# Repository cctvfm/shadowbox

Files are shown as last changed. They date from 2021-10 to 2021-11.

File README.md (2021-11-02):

# shadowbox
Shadowbox is an Open Source optically controlled digital drone synth where parameters are controlled by introducing or blocking light. Based on Emilie Gillet's Plaits Module.

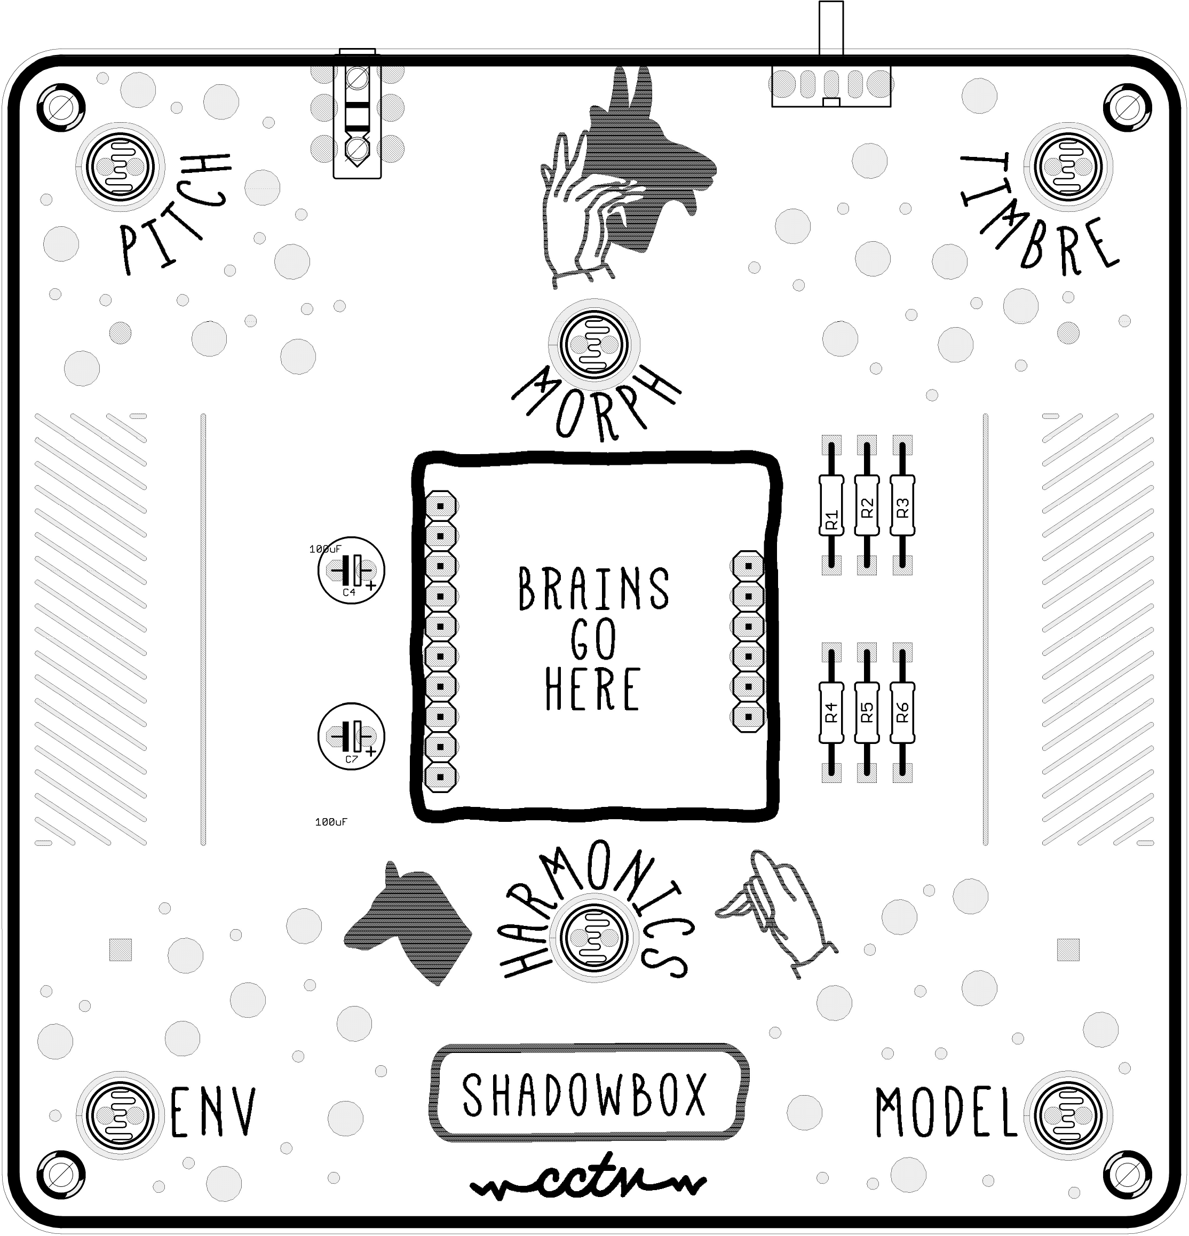
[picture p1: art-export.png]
Main PCB


To Compile code:

Copy entire 'neuzplaits' folder into the 'eurorack' folder in the mutable dev environment.

run 

make -f neuzplaits/bootloader/makefile hex

make -f neuzplaits/makefile

to upload using ST-Link V2:

make -f neuzplaits/makefile upload

'AVR CHICLET' is an alternate brain board using ATMEGA328P. Code to come.

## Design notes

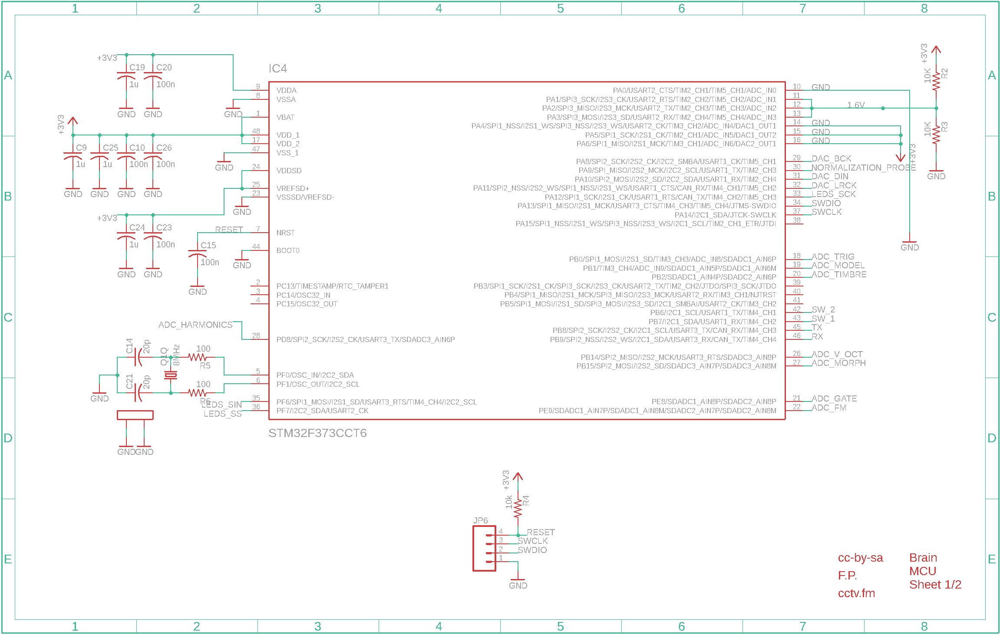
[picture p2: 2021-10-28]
schematic-brain1.png

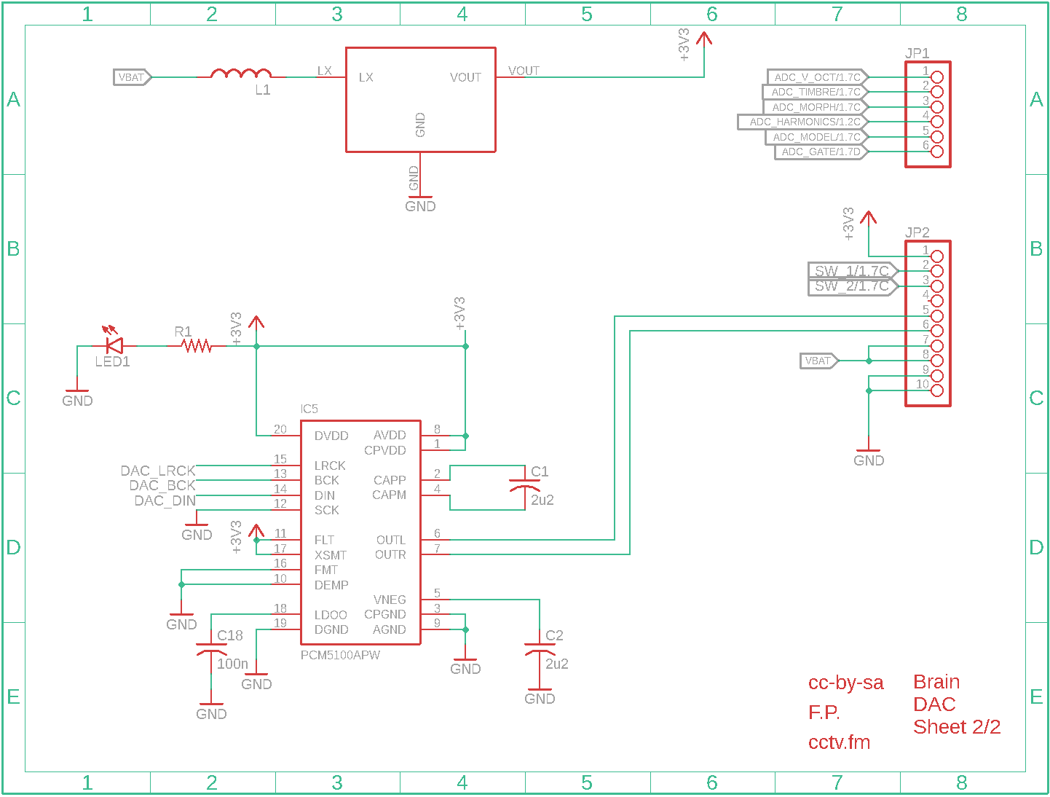
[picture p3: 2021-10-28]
schematic-brain2.png

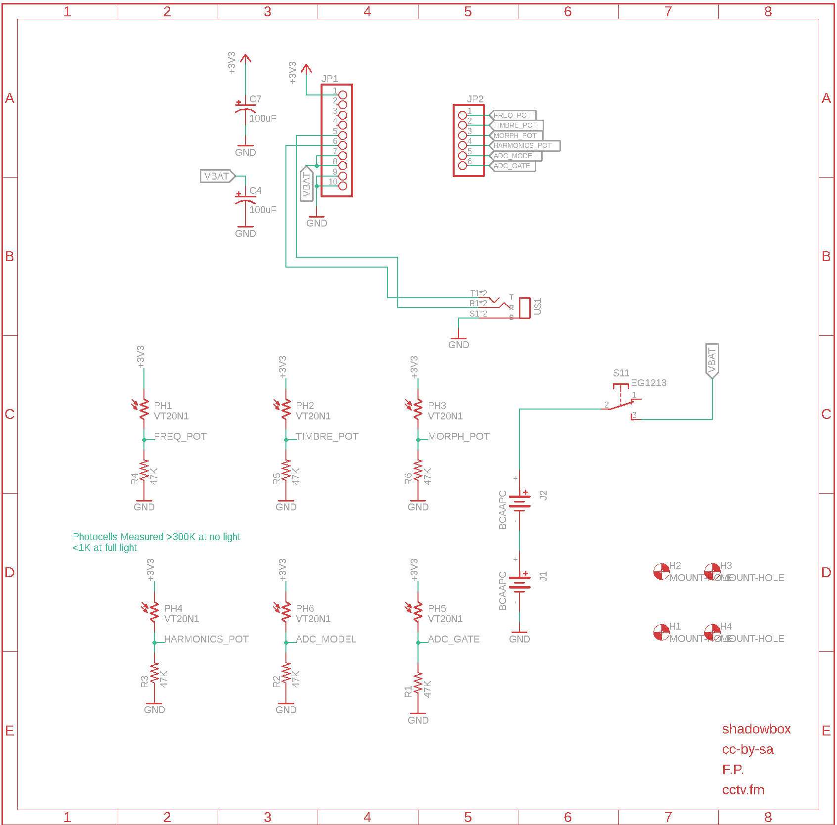
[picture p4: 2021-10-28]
schematic.png

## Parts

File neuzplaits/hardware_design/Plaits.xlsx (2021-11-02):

Plaits, v5.0
Index | Qty | Description | Specs | Value | Package | Ref. Mouser | References
SMT parts
R3, R4, R16, R21, R45, R48, R49, R50, R51 | 9 | Resistor | <=1%, 100mW | 10k | 0402 | 667-ERJ-2RKF1002X
R5, R6, R9, R10 | 4 | Resistor | <=1%, 100mW | 100 | 0402 | 667-ERJ-2RKF1000X
R11, R12, R37 | 3 | Resistor | <=1%, 100mW | 2.2k | 0402 | 667-ERJ-2RKF2201X
R13, R14, R15, R24, R38, R39, R40, R41 | 8 | Resistor | <=1%, 100mW | 100k | 0402 | 667-ERJ-2RKF1003X
R17 | 1 | Resistor | <=1%, 100mW | 56k | 0402 | 667-ERJ-2RKF5602X
R18, R20, R22, R28, R31, R34 | 6 | Resistor | <=1%, 100mW | 33k | 0402 | 667-ERJ-2RKF3302X
R19, R32, R35 | 3 | Resistor | <=1%, 100mW | 20k | 0402 | 667-ERJ-2RKF2002X
R23, R33, R36 | 3 | Resistor | <=1%, 100mW | 120k | 0402 | 667-ERJ-2RKF1203X
R25, R27, R30 | 3 | Resistor | <=1%, 100mW | 200k | 0402 | 667-ERJ-2RKF2003X
R26 | 1 | Resistor | <=1%, 100mW | 110k | 0402 | 667-ERJ-2RKF1103X
R29 | 1 | Resistor | <=1%, 100mW | 140k | 0402 | 667-ERJ-2RKF1403X
R46, R47 | 2 | Resistor | <= 1%, >= 200mW | 1.0k | 0603 | 667-ERJ-PA3D1001V | Panasonic ERJ-PA3D1001V
C1, C2, C13 | 3 | Capacitor, ceramic | >= 25V, X5R | 22u | 1206 | 81-GRM31CR61E226ME5L | Murata GRM31CR61E226ME15L
C3, C7, C16, C22, C30 | 5 | Capacitor, electrolytic | >= 16V | 10u | Panasonic A (3mm) | 647-UWX1C100MCL2 | Nichicon UWX1C100MCL2GB
C4, C5 | 2 | Capacitor, electrolytic | >= 35V | 22u | Panasonic B (4mm) | 647-UCM1V220MCL1GS | Nichicon UCM1V220MCL1GS
C6, C8, C10, C11, C12, C15, C17, C18, C20, C23, C26, C27, C28, C32, C34, C36, C37, C44, C45, C51, C52, C53 | 22 | Capacitor, ceramic | >= 25V, X5R | 100n | 0402 | 81-GRM155R61E104KA7D | Murata GRM155R61E104KA87D
C9, C19, C24, C25, C50 | 5 | Capacitor, ceramic | >= 25V, X6S | 1u | 0402 | 81-GRM155C81E105ME1D | Murata GRM155C81E105ME11D
C14, C21 | 2 | Capacitor, ceramic | >=25V, C0G, <= 5% | 20p | 0402 | 81-GRM1555C1E200JA1D | Murata GRM1555C1E200JA01D
C29, C31 | 2 | Capacitor, ceramic | >= 25V, X5R | 2.2u | 0805 | 810-C2012X5R1E225K | TDK C2012X5R1E225K125AC
C33, C35, C39, C40, C41, C47, C48, C49 | 8 | Capacitor, ceramic | >= 25V, C0G, <= 5% | 1n | 0402 | 81-GRM1555C1H102JA1D | Murata GRM1555C1H102JA01D
C38, C42, C43, C46 | 4 | Capacitor, ceramic | >= 25V, C0G, <= 5% | 100p | 0402 | 81-GRM1555C1H101JA1D | Murata GRM1555C1H101JA01D
C54, C55, C56, C57, C58, C59, C60, C61 | 8 | Ceradiode |  |  | 0603 | 871-B72500D160H60 | Epcos / TDK B72500D160H60
L1 | 1 | Inductor |  | 33u | 0805 | 810-MLZ2012M330WT000 | TDK MLZ2012M330WT000
L2, L3, L4, L5 | 4 | EMI Filter Bead | >= 1k ohm, 300mA |  | 0603 | 710-742792664 | Würth Electronics 742792664
D1, D2 | 2 | 1N5819HW diode |  |  | SOD123 | 621-1N5819HW-F | Diodes Inc 1N5819HW-7-F
D3 | 1 | BAT54SLT1G diode |  |  | SOT23 | 863-BAT54SLT1G | ON Semi BAT54SLT1G (replaces BAT54S)
IC2 | 1 | TLC59281DBQ 16ch LED driver |  |  | TSSOP24 | 595-TLC59281DBQR | Texas Instruments TLC59281DBQR
IC3 | 1 | LD2981ABU33 LDO regulator | 3.3V |  | SOT89-3 | 511-LD2981ABU33 | ST LD2981ABU33TR
IC4 | 1 | STM32F373CCT6, Cortex M4 256k flash |  |  | LQFP48 | 511-STM32F373CCT6 | ST STM32F373CCT6
IC5 | 1 | PCM5100APW Audio DAC |  |  | SSOP20 | 595-PCM5100APWR | Texas Instruments PCM5100APWR
IC6, IC7 | 2 | MCP6004 quad op-amp R2R IO |  |  | TSSOP14 | 579-MCP6004-I/ST | Microchip MCP6004-I/ST
IC8 | 1 | TL072 dual op-amp |  |  | TSSOP8 | 595-TL072CPWR | Texas Instruments TL072CPWR
IC9 | 1 | LM4040 Shunt Vref | C grade (0.5%, 100ppm) | 10V | SOT23 | 595-LM4040C10IDBZR | Texas Instruments LM4040C10IDBZ
Q1 | 1 | Crystal | <= 20ppm | 8MHz | 6mm x 3.6mm | 815-ABMM2-8-E2T | Abracon ABMM2-8.000MHZ-E2-T
PTH parts, top side
IC1 | 1 | DC-DC converter R-78E3.3-0.5 | 3.3V, 500mA |  |  | 919-R-78E3.3-0.5 | Recom R-78E3.3-0.5
J1, J2, J3, J4, J5, J6, J7, J8, J9, J10 | 10 | Vertical jack connector |  |  |  |  | https://www.thonk.co.uk/shop/thonkiconn/
LED1, LED2, LED3, LED4, LED5, LED6, LED7, LED8 | 8 | LED 3mm red/green common anode |  |  |  | 696-SSLLX3059IGWCA | Lumex SSL-LX3059IGW-CA
- | 8 | LED holder, 0.3in |  |  |  | 749-ERM1-300 | Bivar ERM 1-300
R1, R2, R7, R8 | 4 | 10k linear pot, 15mm shaft |  |  |  |  | https://www.thonk.co.uk/shop/alpha-9mm-pots/
R42, R43, R44 | 3 | 10k linear pot, 25mm shaft with marker |  |  |  |  | https://www.thonk.co.uk/shop/ttpots/
SW1, SW2 | 2 | Switch, 6mm |  |  |  | 612-TL1105SP-250 | E-switch TL1105SPF250Q
- | 2 | Cap for switch |  |  |  | 612-1R-BK | E-switch 1RBLK
PTH parts, bottom side
JP8 | 1 | 2x5 male boxed header, 2.54mm pitch |  |  |  | 710-61201021621
PCB |  | 59.0 x 106.7

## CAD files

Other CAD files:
neuzplaits/hardware_design/panel/plaits_v50.dwg

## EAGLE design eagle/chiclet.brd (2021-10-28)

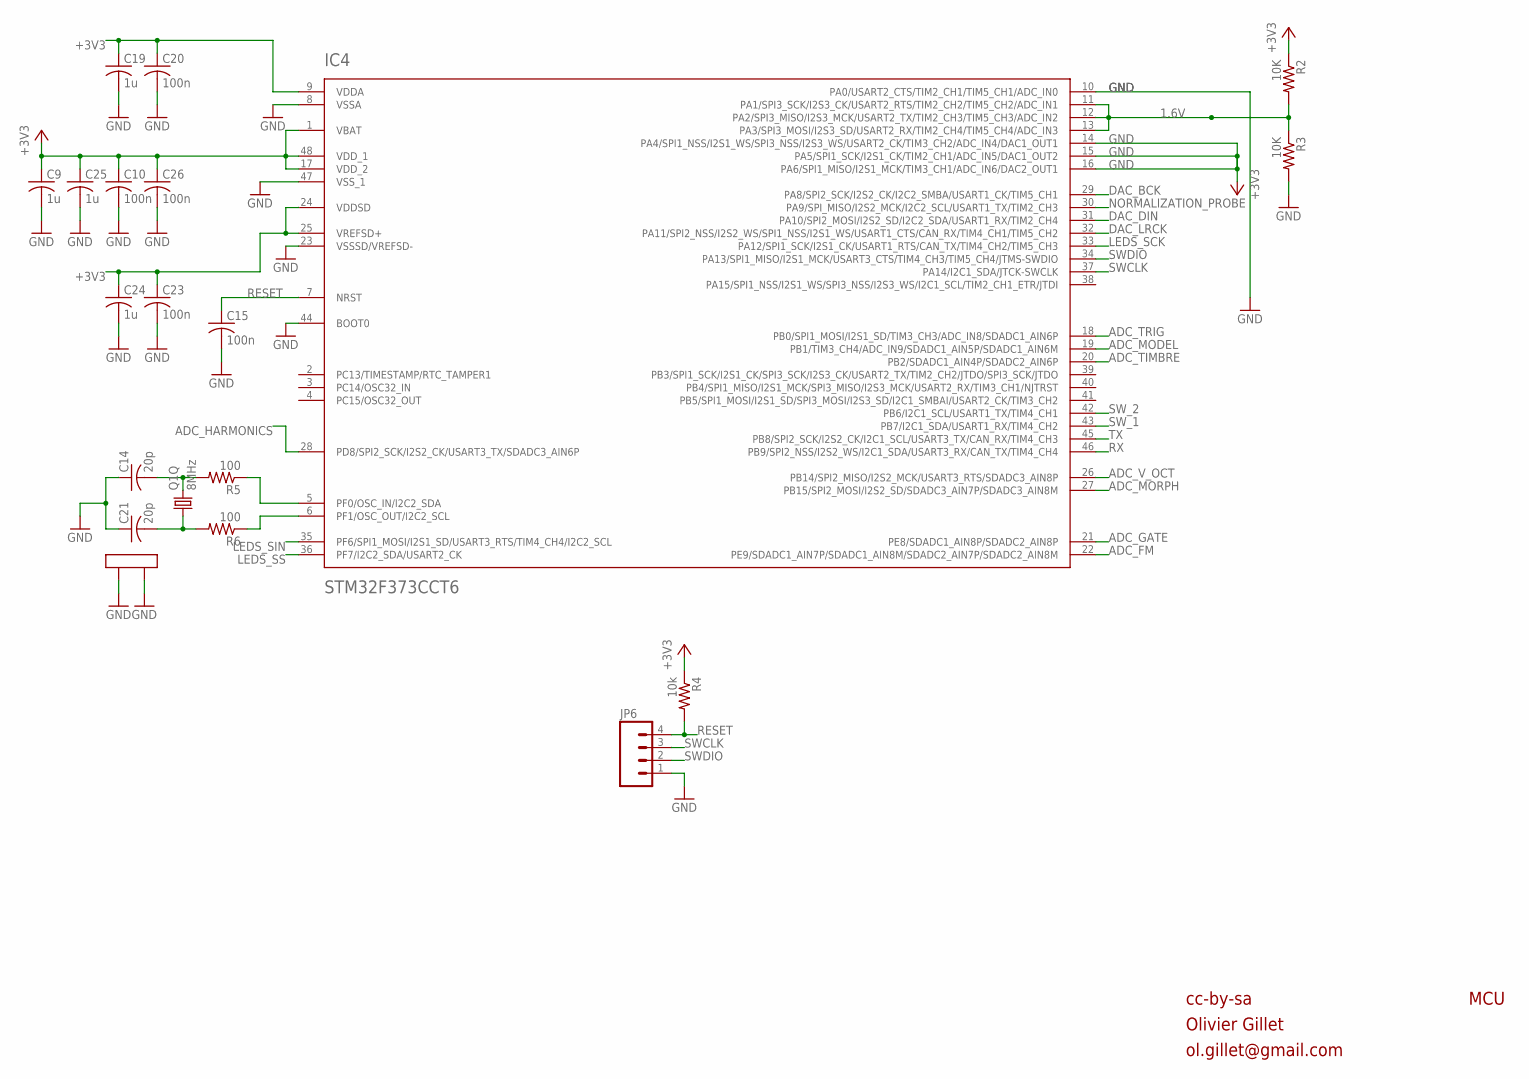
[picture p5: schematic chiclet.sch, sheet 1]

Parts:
C9, C19, C24, C25: 1u; C0805
C10, C15, C20, C23, C26: 100n; C0805
C14, C21: 20p; C0805
IC4: STM32F373CCT6; LQFP48
JP6: M04PTH; 1X04
Q1: 8MHz; CTS406
R2, R3: 10K; M0805
R4: 10k; M0805
R5, R6: 100; M0805

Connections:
1.6V: IC4.11 (PA1/SPI3_SCK/I2S3_CK/USART2_RTS/TIM2_CH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), IC4.12 (PA2/SPI3_MISO/I2S3_MCK/USART2_TX/TIM2_C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), IC4.13 (PA3/SPI3_MOSI/I2S3_SD/USART2_RX/TIM2_CH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), R2.2, R3.1
+3V3: C9.1, C10.1, C19.1, C20.1, C23.1, C24.1, C25.1, C26.1, IC4.1 (VBAT), IC4.9 (VDDA), IC4.14 (PA4/SPI1_NSS/I2S1_WS/SPI3_NSS/I2S3_WS/U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), IC4.15 (PA5/SPI1_SCK/I2S1_CK/TIM2_CH1/ADC_IN5/D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), IC4.16 (PA6/SPI1_MISO/I2S1_MCK/TIM3_CH1/ADC_IN6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), IC4.17 (VDD_2), IC4.24 (VDDSD), IC4.25 (VREFSD+), IC4.48 (VDD_1), R2.1, R4.1; also elsewhere on the board
ADC_FM: IC4.22 (PE9/SDADC1_AIN7P/SDADC1_AIN8M/SDADC2_AI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)
ADC_GATE: IC4.21 (PE8/SDADC1_AIN8P/SDADC2_AIN8P); also elsewhere on the board
ADC_HARMONICS: IC4.28 (PD8/SPI2_SCK/I2S2_CK/USART3_TX/SDADC3_A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); also elsewhere on the board
ADC_MODEL: IC4.19 (PB1/TIM3_CH4/ADC_IN9/SDADC1_AIN5P/SDADC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); also elsewhere on the board
ADC_MORPH: IC4.27 (PB15/SPI2_MOSI/I2S2_SD/SDADC3_AIN7P/SDA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); also elsewhere on the board
ADC_TIMBRE: IC4.20 (PB2/SDADC1_AIN4P/SDADC2_AIN6P); also elsewhere on the board
ADC_TRIG: IC4.18 (PB0/SPI1_MOSI/I2S1_SD/TIM3_CH3/ADC_IN8/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)
ADC_V_OCT: IC4.26 (PB14/SPI2_MISO/I2S2_MCK/USART3_RTS/SDAD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); also elsewhere on the board
DAC_BCK: IC4.29 (PA8/SPI2_SCK/I2S2_CK/I2C2_SMBA/USART1_C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); also elsewhere on the board
DAC_DIN: IC4.31 (PA10/SPI2_MOSI/I2S2_SD/I2C2_SDA/USART1_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); also elsewhere on the board
DAC_LRCK: IC4.32 (PA11/SPI2_NSS/I2S2_WS/SPI1_NSS/I2S1_WS/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); also elsewhere on the board
GND: C9.2, C10.2, C14.1, C15.2, C19.2, C20.2, C21.1, C23.2, C24.2, C25.2, C26.2, IC4.8 (VSSA), IC4.10 (PA0/USART2_CTS/TIM2_CH1/TIM5_CH1/ADC_IN0), IC4.23 (VSSSD/VREFSD-), IC4.44 (BOOT0), IC4.47 (VSS_1), JP6.1, Q1.2 (LID1), Q1.4 (LID2), R3.2; also elsewhere on the board
LEDS_SCK: IC4.33 (PA12/SPI1_SCK/I2S1_CK/USART1_RTS/CAN_TX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)
LEDS_SIN: IC4.35 (PF6/SPI1_MOSI/I2S1_SD/USART3_RTS/TIM4_C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)
LEDS_SS: IC4.36 (PF7/I2C2_SDA/USART2_CK)
unnamed: IC4.5 (PF0/OSC_IN/I2C2_SDA), R5.1
unnamed: IC4.6 (PF1/OSC_OUT/I2C2_SCL), R6.1
unnamed: C14.2, Q1.3 (2), R5.2
unnamed: C21.2, Q1.1, R6.2
NORMALIZATION_PROBE: IC4.30 (PA9/SPI_MISO/I2S2_MCK/I2C2_SCL/USART1_T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)
RESET: C15.1, IC4.7 (NRST), JP6.4, R4.2
RX: IC4.46 (PB9/SPI2_NSS/I2S2_WS/I2C1_SDA/USART3_RX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)
SWCLK: IC4.37 (PA14/I2C1_SDA/JTCK-SWCLK), JP6.3
SWDIO: IC4.34 (PA13/SPI1_MISO/I2S1_MCK/USART3_CTS/TIM4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), JP6.2
SW_1: IC4.43 (PB7/I2C1_SDA/USART1_RX/TIM4_CH2); also elsewhere on the board
SW_2: IC4.42 (PB6/I2C1_SCL/USART1_TX/TIM4_CH1); also elsewhere on the board
TX: IC4.45 (PB8/SPI2_SCK/I2S2_CK/I2C1_SCL/USART3_TX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)

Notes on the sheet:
cc-by-sa
Olivier Gillet
ol.gillet@gmail.com
MCU

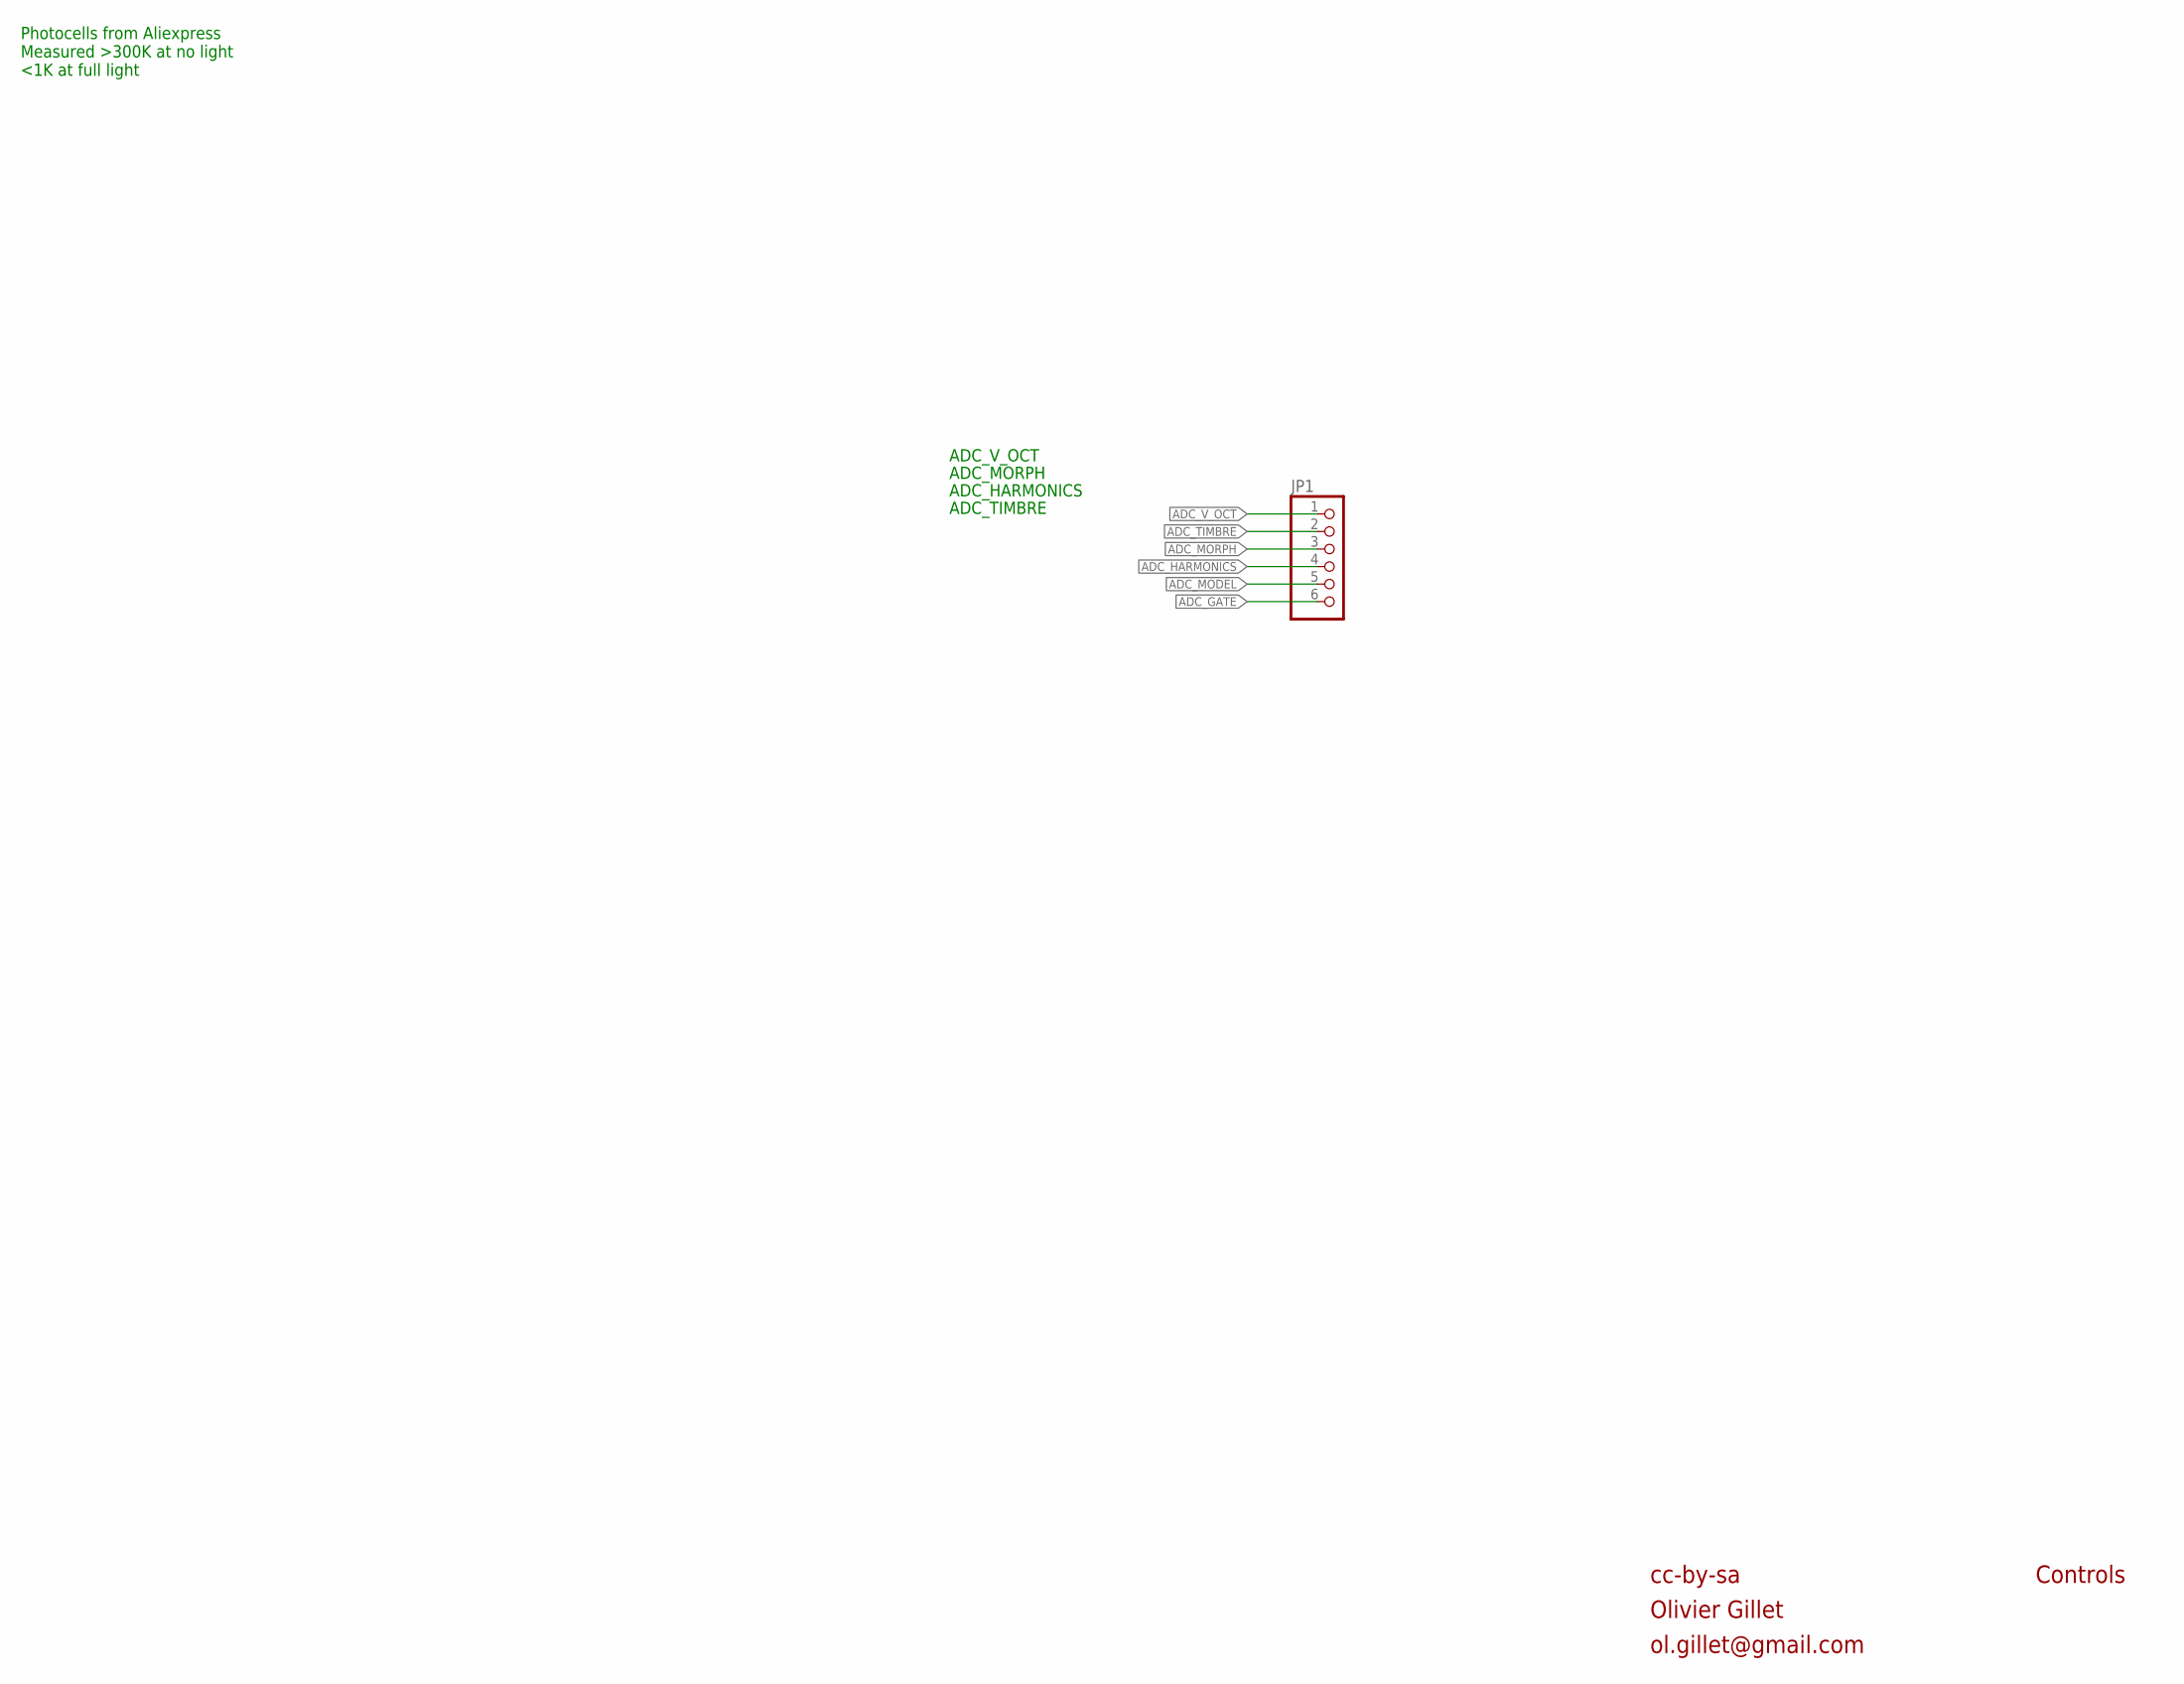
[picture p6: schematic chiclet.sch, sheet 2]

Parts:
JP1: PINHD-1X6; 1X06

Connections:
ADC_GATE: JP1.6; also elsewhere on the board
ADC_HARMONICS: JP1.4; also elsewhere on the board
ADC_MODEL: JP1.5; also elsewhere on the board
ADC_MORPH: JP1.3; also elsewhere on the board
ADC_TIMBRE: JP1.2; also elsewhere on the board
ADC_V_OCT: JP1.1; also elsewhere on the board

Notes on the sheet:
cc-by-sa
Olivier Gillet
ol.gillet@gmail.com
Controls
Photocells from Aliexpress Measured >300K at no light <1K at full light
ADC_V_OCT
ADC_MORPH
ADC_HARMONICS
ADC_TIMBRE

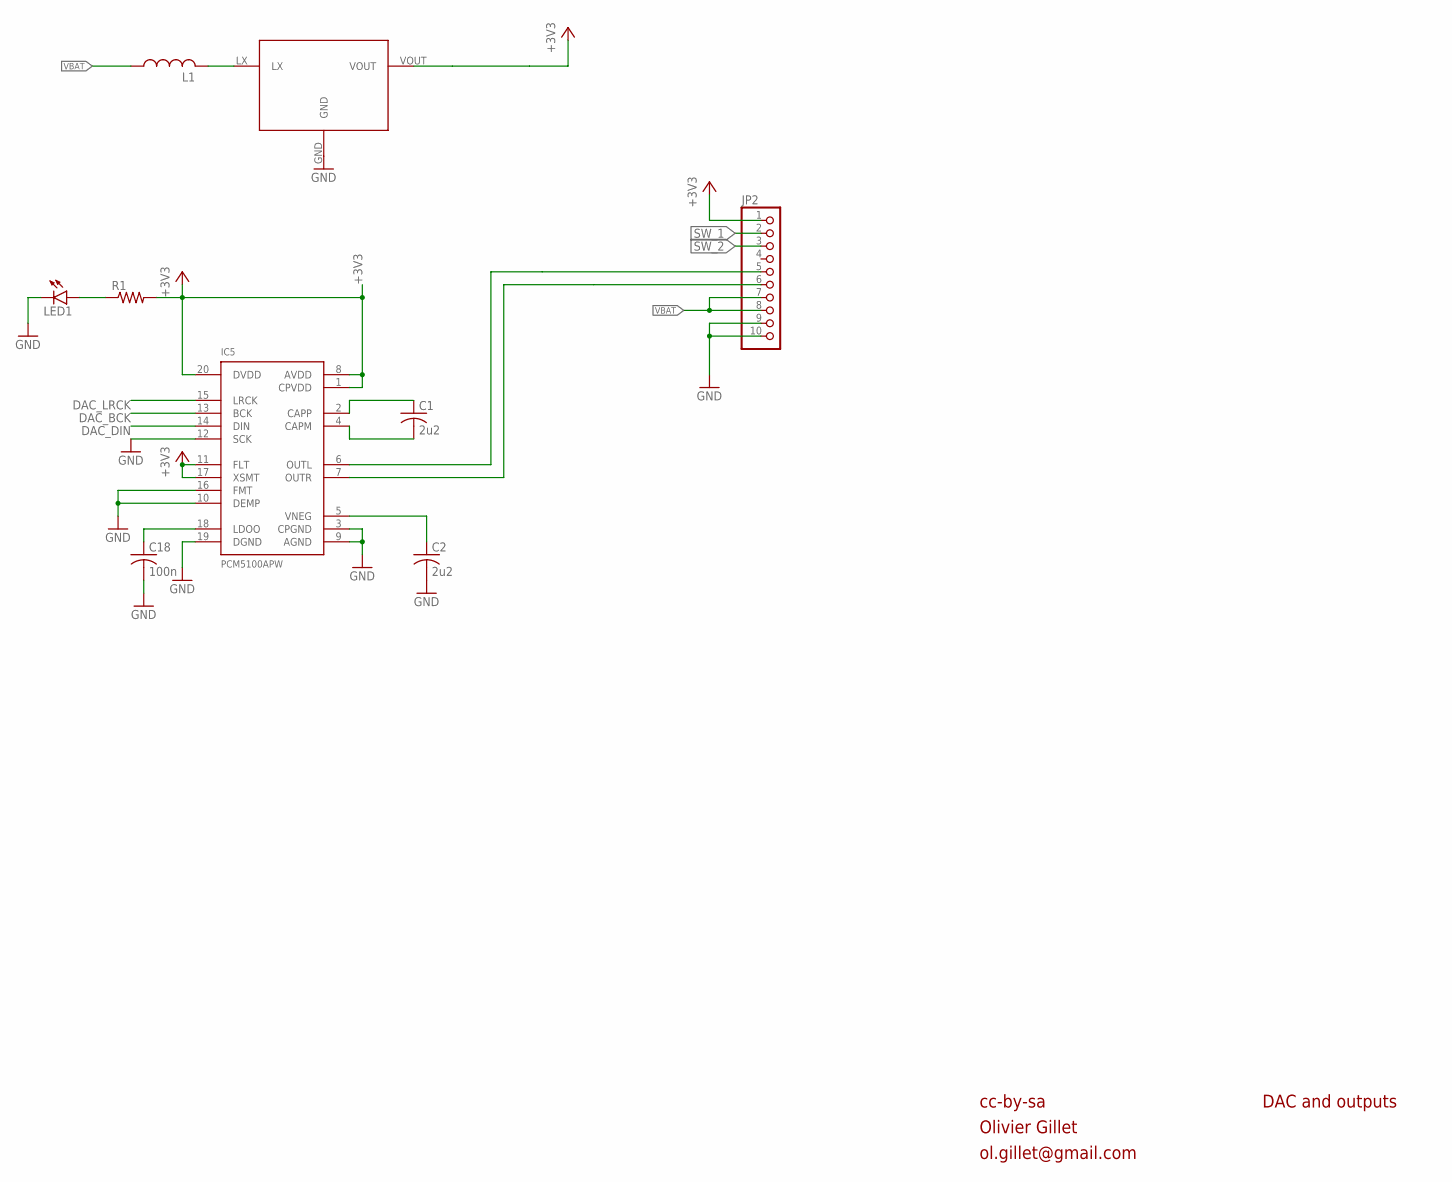
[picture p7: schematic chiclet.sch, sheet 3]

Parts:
C1, C2: 2u2; C0805K
C18: 100n; C0805K
IC5: PCM5100APW; SSOP20
JP2: PINHD-1X10; 1X10
L1: L-USL2825P; L2825P
LED1: LEDSML0805; SML0805
R1: R-US_R0805; R0805
U$1: QX2304L33E; SOT89-R

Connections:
+3V3: IC5.1 (CPVDD), IC5.8 (AVDD), IC5.11 (FLT), IC5.17 (XSMT), IC5.20 (DVDD), JP2.1, R1.2, U$1.VOUT; also elsewhere on the board
DAC_BCK: IC5.13 (BCK); also elsewhere on the board
DAC_DIN: IC5.14 (DIN); also elsewhere on the board
DAC_LRCK: IC5.15 (LRCK); also elsewhere on the board
GND: C2.2, C18.2, IC5.3 (CPGND), IC5.9 (AGND), IC5.10 (DEMP), IC5.12 (SCK), IC5.16 (FMT), IC5.19 (DGND), JP2.9, JP2.10, LED1.C, U$1.GND; also elsewhere on the board
unnamed: LED1.A, R1.1
unnamed: C2.1, IC5.5 (VNEG)
unnamed: L1.2, U$1.LX
unnamed: C1.1, IC5.2 (CAPP)
unnamed: IC5.6 (OUTL), JP2.5
unnamed: IC5.7 (OUTR), JP2.6
unnamed: C1.2, IC5.4 (CAPM)
unnamed: C18.1, IC5.18 (LDOO)
SW_1: JP2.2; also elsewhere on the board
SW_2: JP2.3; also elsewhere on the board
VBAT: JP2.7, JP2.8, L1.1

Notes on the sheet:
cc-by-sa
Olivier Gillet
ol.gillet@gmail.com
DAC and outputs

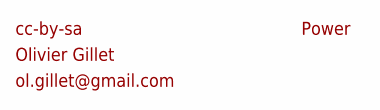
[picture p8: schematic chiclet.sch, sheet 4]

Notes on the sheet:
cc-by-sa
Olivier Gillet
ol.gillet@gmail.com
Power

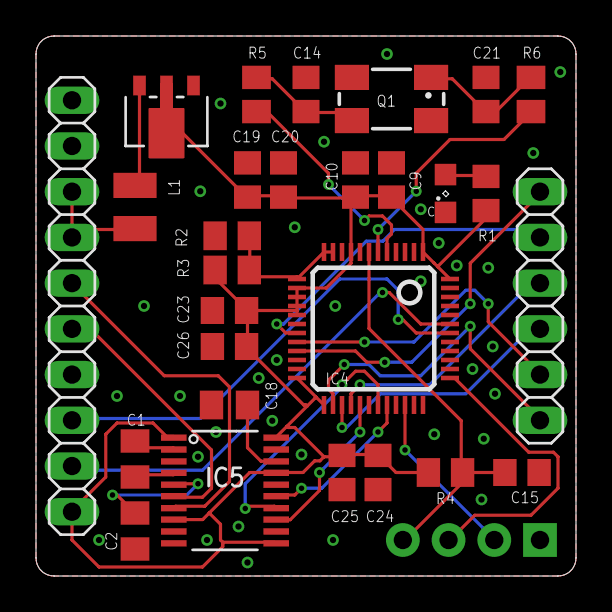
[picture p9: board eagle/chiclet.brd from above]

Board: 2 copper layers, 30.0 x 30.0 mm, 29 parts (1 on the bottom side), 30 nets.

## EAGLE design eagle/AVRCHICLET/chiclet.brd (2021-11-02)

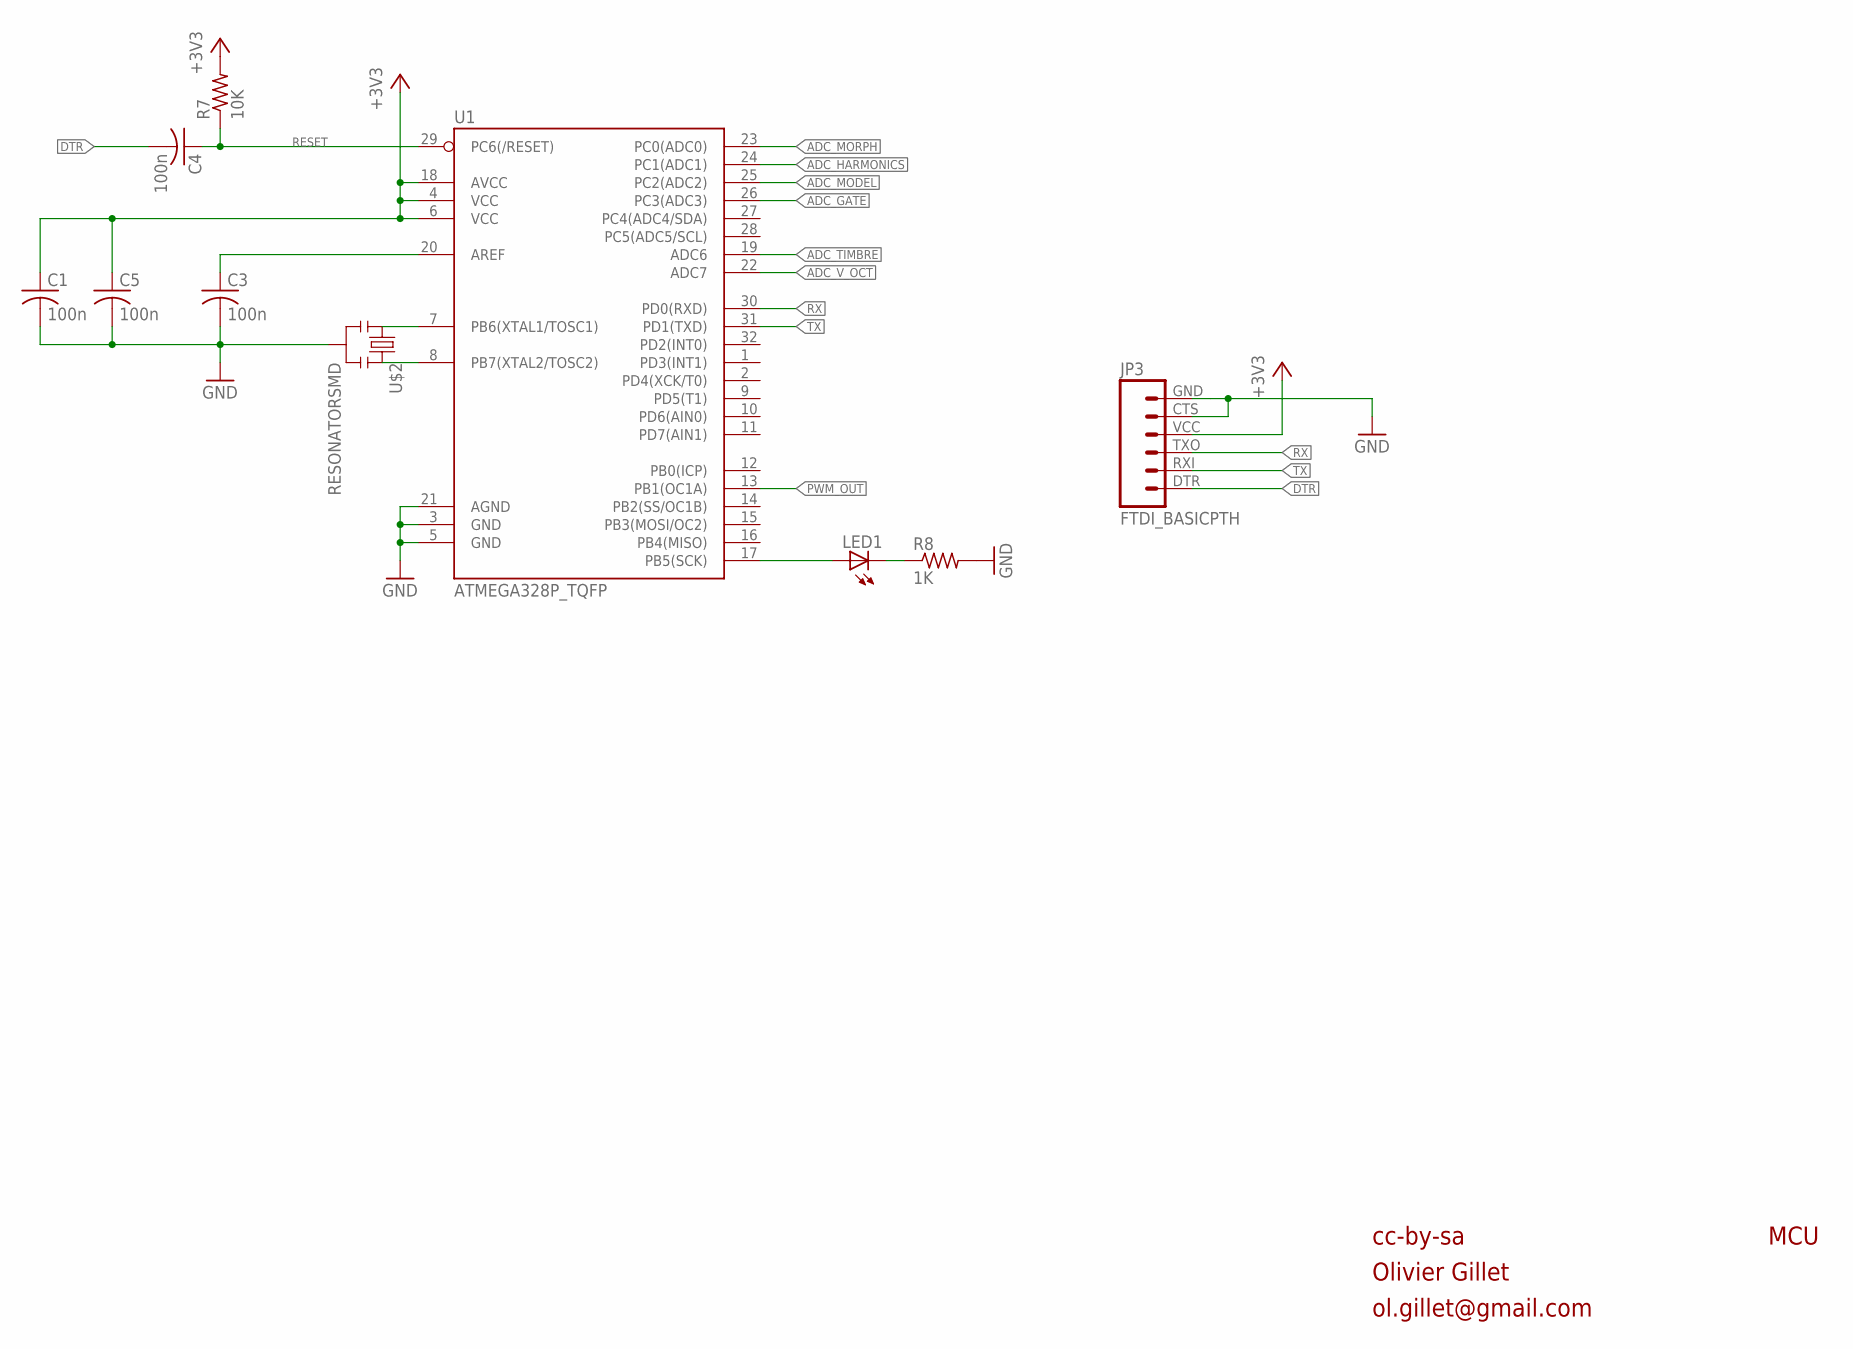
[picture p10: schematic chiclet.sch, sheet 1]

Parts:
C1, C3, C4, C5: 100n; C0805
JP3: FTDI_BASICPTH; FTDI_BASIC
LED1: LED-0805; LED-805
R7: 10K; M0805
R8: 1K; M0805
U1: ATMEGA328P_TQFP; TQFP32-08
U$2: RESONATORSMD; RESONATOR-SMD

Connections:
+3V3: C1.1, C5.1, JP3.VCC (4), R7.2, U1.4 (VCC), U1.6 (VCC), U1.18 (AVCC); also elsewhere on the board
ADC_GATE: U1.26 (PC3(ADC3)); also elsewhere on the board
ADC_HARMONICS: U1.24 (PC1(ADC1)); also elsewhere on the board
ADC_MODEL: U1.25 (PC2(ADC2)); also elsewhere on the board
ADC_MORPH: U1.23 (PC0(ADC0)); also elsewhere on the board
ADC_TIMBRE: U1.19 (ADC6); also elsewhere on the board
ADC_V_OCT: U1.22 (ADC7); also elsewhere on the board
DTR: C4.2, JP3.DTR (1)
GND: C1.2, C3.2, C5.2, JP3.CTS (5), JP3.GND (6), R8.2, U1.3 (GND), U1.5 (GND), U1.21 (AGND), U$2.2; also elsewhere on the board
unnamed: U1.7 (PB6(XTAL1/TOSC1)), U$2.1
unnamed: U1.8 (PB7(XTAL2/TOSC2)), U$2.3
unnamed: C3.1, U1.20 (AREF)
unnamed: LED1.A, U1.17 (PB5(SCK))
unnamed: LED1.C, R8.1
PWM_OUT: U1.13 (PB1(OC1A)); also elsewhere on the board
RESET: C4.1, R7.1, U1.29 (PC6(/RESET))
RX: JP3.TXO (3), U1.30 (PD0(RXD))
TX: JP3.RXI (2), U1.31 (PD1(TXD))

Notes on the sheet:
cc-by-sa
Olivier Gillet
ol.gillet@gmail.com
MCU


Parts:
JP1: PINHD-1X6; 1X06

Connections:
ADC_GATE: JP1.6; also elsewhere on the board
ADC_HARMONICS: JP1.4; also elsewhere on the board
ADC_MODEL: JP1.5; also elsewhere on the board
ADC_MORPH: JP1.3; also elsewhere on the board
ADC_TIMBRE: JP1.2; also elsewhere on the board
ADC_V_OCT: JP1.1; also elsewhere on the board

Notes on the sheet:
cc-by-sa
Olivier Gillet
ol.gillet@gmail.com
Controls
Photocells from Aliexpress Measured >300K at no light <1K at full light
ADC_V_OCT
ADC_MORPH
ADC_HARMONICS
ADC_TIMBRE

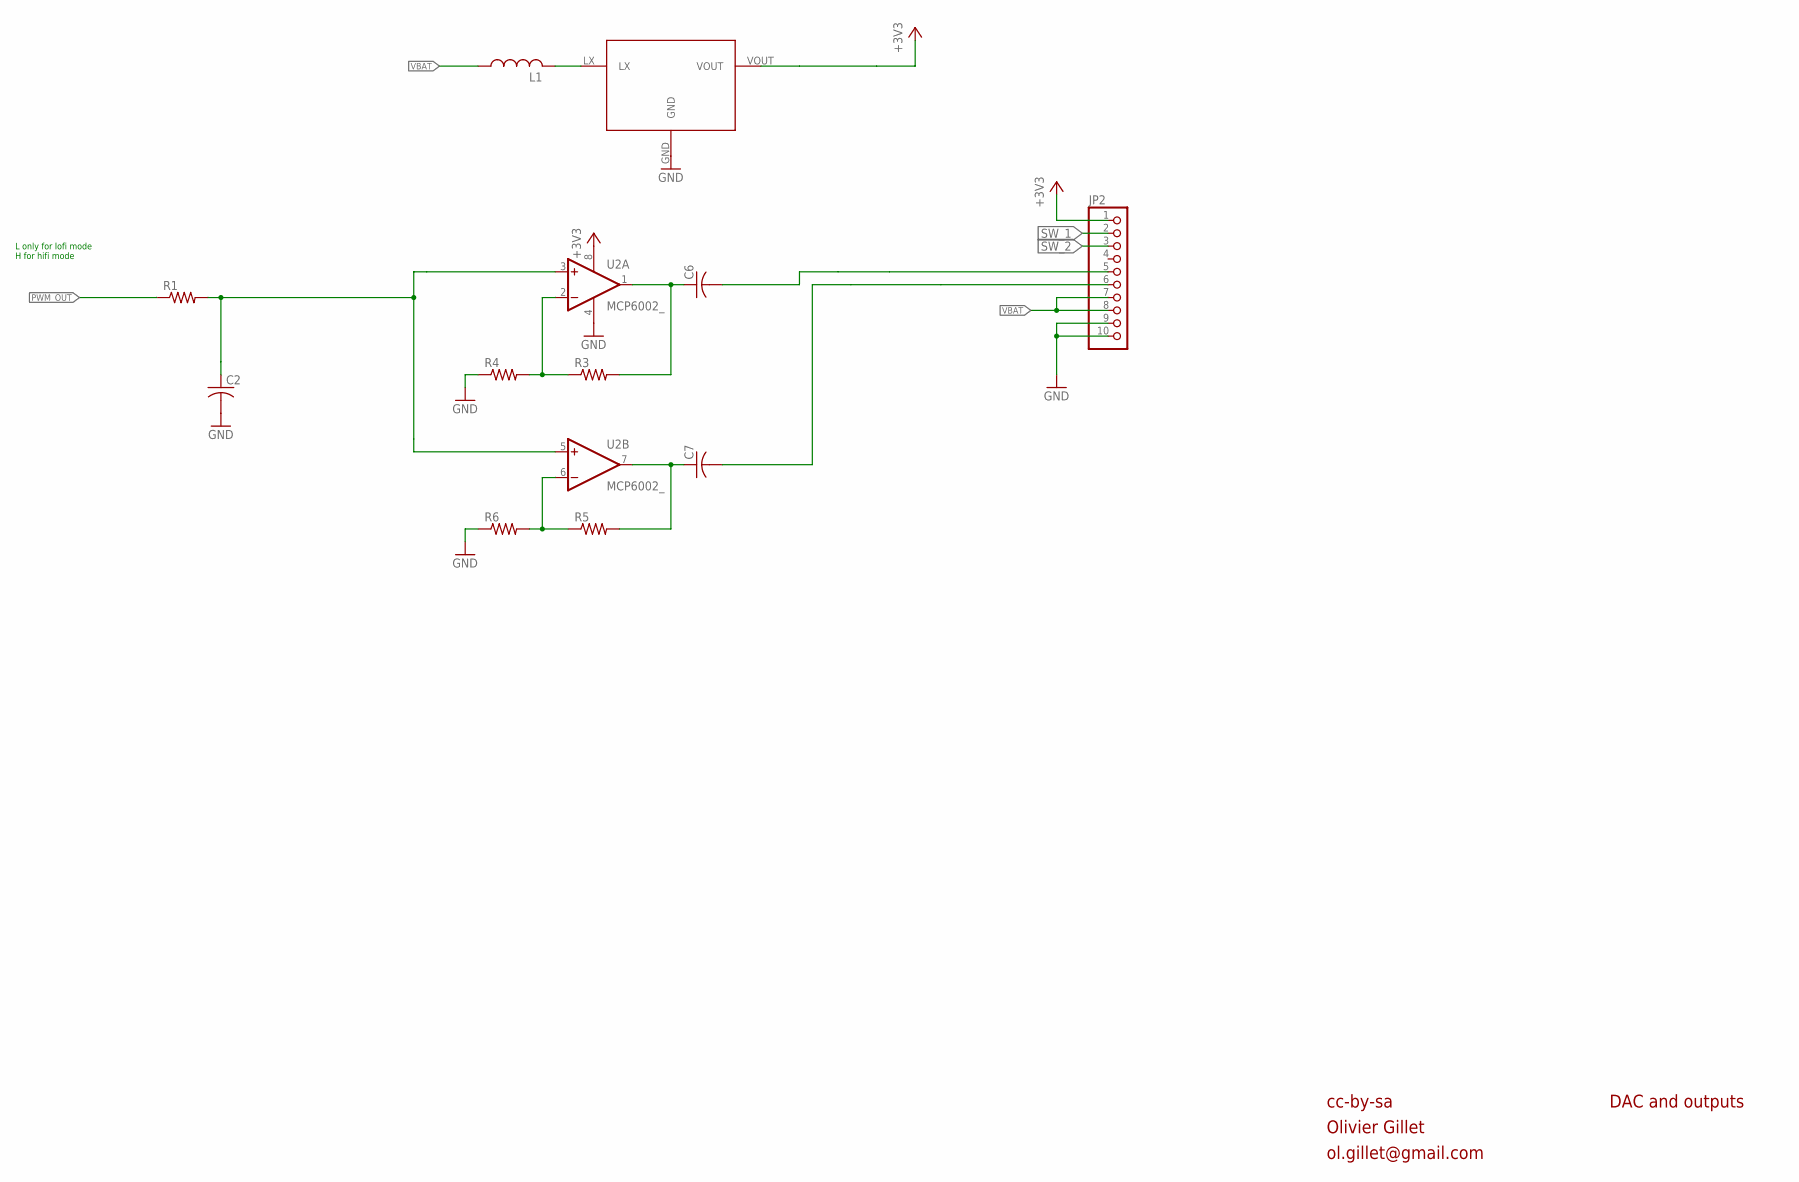
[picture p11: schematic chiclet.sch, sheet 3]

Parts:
C2, C6, C7: C-USC0805; C0805
JP2: PINHD-1X10; 1X10
L1: L-USL2825P; L2825P
R1, R3, R4, R5, R6: R-US_R0805; R0805
U2: MCP6002_; SO08
U$1: QX2304L33E; SOT89-R

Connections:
+3V3: JP2.1, U2.8 (V+), U$1.VOUT; also elsewhere on the board
GND: C2.2, JP2.9, JP2.10, R4.1, R6.1, U2.4 (V-), U$1.GND; also elsewhere on the board
unnamed: L1.2, U$1.LX
unnamed: C2.1, R1.2, U2.3 (+IN), U2.5 (+IN)
unnamed: C6.2, JP2.5
unnamed: C7.2, JP2.6
unnamed: R3.1, R4.2, U2.2 (-IN)
unnamed: R5.1, R6.2, U2.6 (-IN)
unnamed: C7.1, R5.2, U2.7 (OUT)
unnamed: C6.1, R3.2, U2.1 (OUT)
PWM_OUT: R1.1; also elsewhere on the board
SW_1: JP2.2
SW_2: JP2.3
VBAT: JP2.7, JP2.8, L1.1

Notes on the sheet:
cc-by-sa
Olivier Gillet
ol.gillet@gmail.com
DAC and outputs
L only for lofi mode H for hifi mode

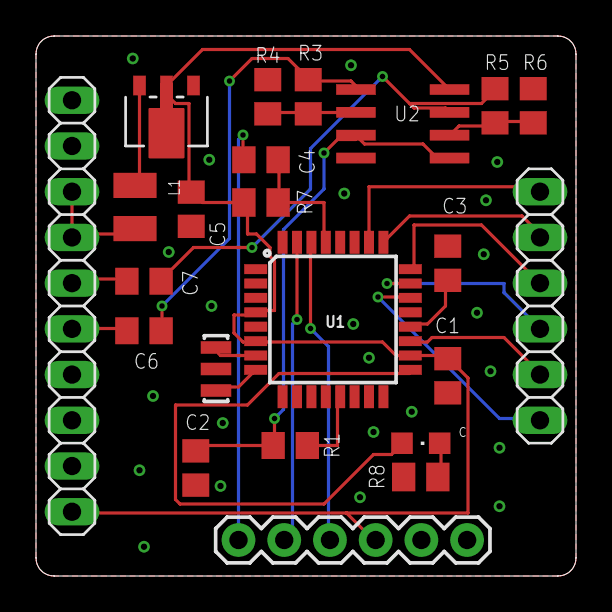
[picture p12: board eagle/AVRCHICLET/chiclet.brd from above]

Board: 2 copper layers, 30.0 x 30.0 mm, 23 parts (0 on the bottom side), 27 nets.

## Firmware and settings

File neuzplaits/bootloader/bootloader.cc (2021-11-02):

// Copyright 2016 Emilie Gillet.
// 
// Author: Emilie Gillet (emilie.o.gillet@gmail.com)
// 
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
// See http://creativecommons.org/licenses/MIT/ for more information.

#include <stm32f37x_conf.h>
#include <cstring>

#include "stmlib/system/bootloader_utils.h"
#include "stmlib/system/flash_programming.h"
#include "stmlib/system/system_clock.h"

#include "stm_audio_bootloader/qpsk/packet_decoder.h"
#include "stm_audio_bootloader/qpsk/demodulator.h"

#include "plaits/drivers/audio_dac.h"
#include "plaits/drivers/firmware_update_adc.h"
#include "plaits/drivers/leds.h"
#include "plaits/drivers/switches.h"

extern "C" {

void NMI_Handler() { }
void HardFault_Handler() { while (1); }
void MemManage_Handler() { while (1); }
void BusFault_Handler() { while (1); }
void UsageFault_Handler() { while (1); }
void SVC_Handler() { }
void DebugMon_Handler() { }
void PendSV_Handler() { }

}

using namespace plaits;
using namespace std;
using namespace stm_audio_bootloader;
using namespace stmlib;

const double kSampleRate = 48000.0;
const double kModulationRate = 6000.0;
const double kBitRate = 12000.0;
const uint32_t kStartAddress = 0x08008000;
const uint16_t kPacketsPerPage = PAGE_SIZE / kPacketSize;

enum UiState {
  UI_STATE_WAITING,
  UI_STATE_RECEIVING,
  UI_STATE_ERROR,
  UI_STATE_WRITING
};

AudioDac audio_dac;
FirmwareUpdateAdc adc;
Leds leds;
Switches switches;
PacketDecoder decoder;
Demodulator demodulator;

int discard_samples = 8000;
int32_t peak = 0;
int32_t gain_pot = 0;
uint32_t current_address;
uint16_t packet_index;
uint8_t rx_buffer[PAGE_SIZE];

volatile bool switch_released = false;
volatile UiState ui_state;

inline void UpdateLeds() {
  leds.Clear();
  
  // Show bargraph on the upper 4 LEDs.
  int32_t pwm = system_clock.milliseconds() & 15;
  leds.set(3, (peak >> 9) > pwm ? LED_COLOR_GREEN : 0);
  leds.set(2, ((peak - 8192) >> 9) >= pwm ? LED_COLOR_GREEN : 0);
  leds.set(1, ((peak - 16384) >> 9) >= pwm ? LED_COLOR_YELLOW : 0);
  leds.set(0, ((peak - 16384 - 8192) >> 9) >= pwm ? LED_COLOR_RED : 0);
  
  // Show status info on the lower 4 LEDs.
  switch (ui_state) {
    case UI_STATE_WAITING:
      {
        bool on = system_clock.milliseconds() & 128;
        for (int i = 4; i < 8; ++i) {
          leds.set(i, on ? LED_COLOR_YELLOW : LED_COLOR_OFF);
        }
      }
      break;

    case UI_STATE_RECEIVING:
      {
        int stage = (system_clock.milliseconds() >> 7) & 3;
        leds.set(stage + 4, LED_COLOR_GREEN);
      }
      break;

    case UI_STATE_ERROR:
      {
        bool on = system_clock.milliseconds() & 256;
        for (int i = 0; i < 8; ++i) {
          leds.set(i, on ? LED_COLOR_RED : LED_COLOR_OFF);
        }
      }
      break;

    case UI_STATE_WRITING:
      {
        for (uint8_t i = 4; i < 8; ++i) {
          leds.set(i, LED_COLOR_GREEN);
        }
      }
      break;
    }
  leds.Write();
}

extern "C" {
  
void SysTick_Handler() {
  system_clock.Tick();
  switches.Debounce();
  if (switches.released(Switch(0))) {
    switch_released = true;
  }
  UpdateLeds();
}
  
}

void ProgramPage(const uint8_t* data, size_t size) {
  FLASH_Unlock();
  FLASH_ErasePage(current_address);
  const uint32_t* words = static_cast<const uint32_t*>(
      static_cast<const void*>(data));
  for (size_t written = 0; written < size; written += 4) {
    FLASH_ProgramWord(current_address, *words++);
    current_address += 4;
  }
}

void FillBuffer(AudioDac::Frame* output, size_t size) {
  gain_pot = (adc.gain_pot() + 4095 * gain_pot) >> 12;
  int32_t sample = 32768 - static_cast<int32_t>(adc.sample());
  adc.Convert();

  int32_t gain = ((gain_pot >> 1) * gain_pot >> 21) + 128;
  sample = sample * gain >> 8;
  CONSTRAIN(sample, -32767, 32767)
  
  int32_t rect = abs(sample);
  peak = rect > peak ? rect : (rect + 32767 * peak) >> 15;

  if (!discard_samples) {
    demodulator.PushSample(2048 + (sample >> 4));
  } else {
    --discard_samples;
  }
  output->l = -sample;
  output->r = -sample;
}

void InitializeReception() {
  decoder.Init(1000, true);
  demodulator.Init(
      kModulationRate / kSampleRate * 4294967296.0,
      kSampleRate / kModulationRate,
      2.0 * kSampleRate / kBitRate);
  demodulator.SyncCarrier(true);
  decoder.Reset();
  current_address = kStartAddress;
  packet_index = 0;
  ui_state = UI_STATE_WAITING;
}

void Init() {
  adc.Init();
  leds.Init();
  switches.Init();
  audio_dac.Init(48000, 1);
  audio_dac.Start(&FillBuffer);
  SysTick_Config(F_CPU / 1000);
}

int main(void) {
  Init();
  InitializeReception();
  
  bool exit_updater = !switches.pressed_immediate(Switch(0));
  while (!exit_updater) {
    bool error = false;

    if (demodulator.state() == DEMODULATOR_STATE_OVERFLOW) {
      error = true;
    } else {
      demodulator.ProcessAtLeast(32);
    }
    
    while (demodulator.available() && !error && !exit_updater) {
      uint8_t symbol = demodulator.NextSymbol();
      PacketDecoderState state = decoder.ProcessSymbol(symbol);
      switch (state) {
        case PACKET_DECODER_STATE_OK:
          {
            ui_state = UI_STATE_RECEIVING;
            memcpy(
                rx_buffer + (packet_index % kPacketsPerPage) * kPacketSize,
                decoder.packet_data(),
                kPacketSize);
            ++packet_index;
            if ((packet_index % kPacketsPerPage) == 0) {
              ui_state = UI_STATE_WRITING;
              ProgramPage(rx_buffer, PAGE_SIZE);
              decoder.Reset();
              demodulator.SyncCarrier(false);
              ui_state = UI_STATE_RECEIVING;
            } else {
              decoder.Reset();
              demodulator.SyncDecision();
            }
          }
          break;
        case PACKET_DECODER_STATE_ERROR_CRC:
        case PACKET_DECODER_STATE_ERROR_SYNC:
          error = true;
          break;
          break;
        case PACKET_DECODER_STATE_END_OF_TRANSMISSION:
          exit_updater = true;
          break;
        default:
          break;
      }
    }
    
    if (error) {
      ui_state = UI_STATE_ERROR;
      switch_released = false;
      while (!switch_released);  // Polled in ISR
      InitializeReception();
    }
  }
  
  adc.DeInit();
  audio_dac.Stop();
  Uninitialize();
  JumpTo(kStartAddress);
  while (1) { }
}

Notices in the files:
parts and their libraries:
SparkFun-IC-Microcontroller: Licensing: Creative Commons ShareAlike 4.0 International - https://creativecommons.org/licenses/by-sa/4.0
